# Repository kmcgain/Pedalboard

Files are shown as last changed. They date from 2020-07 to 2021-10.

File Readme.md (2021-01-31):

# Pedal Board
## Introduction

After seeing [this post](https://forum.fractalaudio.com/threads/diy-axe-fx-foot-controller-for-50-open-project.119882) I decided to put together my own pedal board for controlling my Axe Fx III. Rather than having a single screen however to display current preset information I wanted a screen per button to provide context sensitive information on each function.

The design includes:
* 3x5 momentary footswitch, lcd screen pairs. 
  * The LCD screen is a 1.8" 128x160px TFT SPI (ST7735 driver). 
* 7 pin MIDI in/out + phantom power on input
* 2 1/4" expression pedal inputs
* 9v adapter input

Layout 1
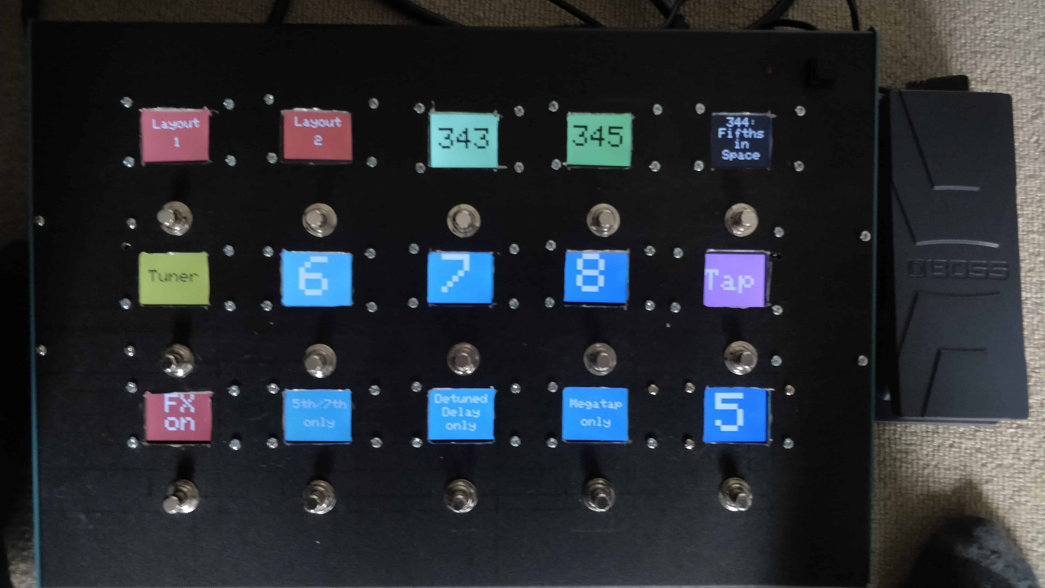
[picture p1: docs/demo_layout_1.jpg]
Layout 1


Layout 2
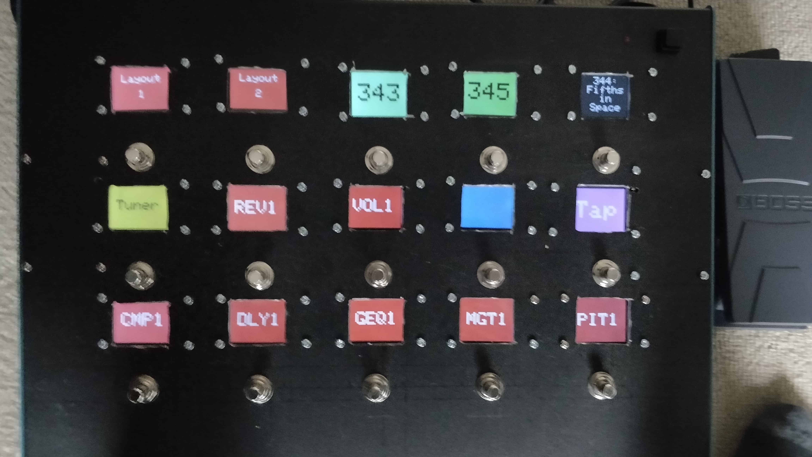
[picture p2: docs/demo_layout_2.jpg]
Layout 2


### Micro-controller
The Arduino Due was chosen due to the number of pins available, support for controlling many SPI devices concurrently, increased clock-speed over the Arduino Mega.

### Construction
A standard hammond enclosure was used, CAD designs were developed using FreeCad and available under [docs](docs). Note these designs were used to get a sense of proportions, layout. The designs aren't comprehensive and the final layout was not millimetre perfect.

[View the circuit diagram](docs/schematic.png)

## Software
The software was written from scratch with the exception of the great [Tysonit library](https://forum.fractalaudio.com/threads/arduino-axe-fx-control-library.147477/) and included Arduino libraries.

Current tweaks to out of the box software:
* Increased Arduino Due buffer size in {User folder}\AppData\Local\Arduino15\packages\arduino\hardware\sam\1.6.12\cores\arduino\RingBuffer.h to 512
* TFT Screen 
    - Need to modify User_Setup file for tft_eSpi lib. - {My Documents}\Arduino\libraries\TFT_eSPI\User_Setup.h
    - You can find my version of these settings at config/User_Setup.h

## Features
NOTE: Some of the below are still in development (marked in italics)
* Button short press, long press, hold
  * Hold allows for streaming multiple actions as opposed to long press which is an instantaneous single function - for example increase volume in increments while holding (I haven't yet assigned to any function..)
  * Functions can be assigned independently and screens will display these assignments independently
* Layouts
  * A layout is a set of functions assigned to buttons
  * A function can be assigned to switch layouts
* Functions
  * Preset/scene increment,decrement,select. Can increment/decrement by 1 or more. Select allows for an arbitrary preset/scene number to be selected eg. jump to preset 100
  * Expression pedal switch
    * *Although 2 expression pedals are supported, if you want to use 1 pedal but switch between controlling volume, wah, pitch or others a button press can do this - effectively changing expression pedal 1/2 to become 1-4.* (TODO)
  * Tap tempo - LED on front panel in sync
  * Tuner toggle + tuner display
  * Mute button
  * Stomp box - bypass drive, delay and other functions
    * Display colour per type, dimmed display when already bypassed  

### Design choices
Button presses signalled by interrupts - priority given to recording presses rather than screen updates / sending axe messages. 

A tape data structure is used for recording button events. This just creates a loop so if more button events occur in between processing cycles than we can fit in memory it will write over the earliest recorded events. This gives preference to processing the last action rather than dropping the latest actions if there is overflow as would be the case with a straight array implementation.

Core domain project is not coupled to Arduino or Tysonit. This allows for unit testing of the majority of the solution. The unit tests need to be extended further.

### Getting Started
After cloning the repository, use the following scripts to work with the program:
build.ps1 (does a single build of the code, no arduino needed)
upload.ps1 (this will build and upload to the arduino. It will ask you to select the com port used by arduino)
monitor.ps1 (you can run this independently of uploads to read the log output from the arduino)

Please visit the [Build Tutorial](docs/tutorial.md) for information on how to construct your own system
For details on how to work with the software visit [Software Tutorial](docs/tutorial-software.md)

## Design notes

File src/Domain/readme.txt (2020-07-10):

Shared Cross Platform C++ Project : For more information see http://www.visualmicro.com

Arduino shared projects allow code to be shared in multiple projects.

It is important to 'Add' a 'Reference' to 'Shared Projects' from the master Arduino project that uses the shared code.

It is also important to understand that, during compilation, shared project code is combined in a temporary folder along with the main project code. Arduino compile usually involves a temp folder therefore this way of working ensures that code could be manually combined and developed with a different IDE in the future.

Visual Studio will display intellisense based on the platform/board that has been specified for the currently active "Startup Project" of the current solution.

The Arduino IDE will also compile code that exists in an \src sub folder and it's children. Adhering to the same structure will also protect your code and allow compilation outside Visual Micro or a custom build tool. 

Suggestion: Because code is combined during compilation duplicate source code file names can be avoided with by structuring code as follows:-

SharedProject1
	src\SharedProject1\SharedProject1.cpp
	src\SharedProject1\SharedProject1.h
	
SharedProject2
	src\SharedProject2\SharedProject2.cpp
	src\SharedProject2\SharedProject2.h
	
When combined into the temp build folder during build of MainArduinoProject1, the structure will end like this:-

MainArduinoProject1
MainArduinoProject1.ino
	src\SharedProject1\SharedProject1.cpp
	src\SharedProject1\SharedProject1.h
	src\SharedProject2\SharedProject2.cpp
	src\SharedProject2\SharedProject2.h

blog: http://www.visualmicro.com/post/2016/05/27/Sharing-code-between-projects.aspx

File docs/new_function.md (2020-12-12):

# How to add a new function

The example I'll use here is adding a mute function. 

## Requirements
* This function should by default by unmuted
* The screen should display 'Mute' when unmuted
* The screen should display 'Unmute' when muted
* Pressing the footswitch should:
  * Change the state from muted to unmuted and vice-versa
  * Send a CC message to Axe FX for CC# 100 with a value of 127 when unmuting and a value of 0 when muting

## Steps
1. Define a new function type in Domain/function/function_type.h and assign the next enum number
   1. Eg. ftMute = 14
2. Define a FunctionState type to store our Muted/Unmuted state. This will be stored against the Control and can be accessed during button execution or screen updates
   1. Function states are designed to be reused across functions so keep them generic. In our case we don't have a boolean based state so we introduce a ToggleFunctionState in Domain/function/function_state.h
   2. The new class should inherit from public Function
   3. It should have a boolean field to represet our toggle position and appropriate functions to modify / return this state.
3. Define a new function class in Domain/function called mute.h
   1. All functions must implement the Name, Type public functions and execute, createState protected functions
      1. Name can be "Mute"
      2. Type should be the new enum value ftMute
      3. createState will return the new ToggleFunctionState
      4. execute should implement the action to run when the button is pressed. In our case we know we need to update our toggle state so the screen can be updated, but also we need to talk to our AxeFx so we'll delegate to the AxeController for this job
4. Add a 'mute' function to Domain/axe_controller.h that accepts a boolean indicating if we should send a mute or unmute
5. Add a 'mute' function to Pedalboard/Axe/axe_controller.cpp
   1. The mute function will call axe.sendControlChange with a CC number of 100 and cc value of 127 or 0 based on toggle flag
6. Modify Domain/function/function_factory.h to add a Mute() function
7. Modify Domain/function/function_factory.cpp to add a Mute() function
   1. This will return a new instance of the MuteFunction we previously defined
8. Modify Domain/layout_definition.h to add a new FunctionName enum member for mute
   1. This is different to the function type - for example with scene selection we have multiple scene selection functions all of the same function type
9.  Modify Domain/layout_manager.cpp setup_functions function to call the function factory and store the mute function instance in the functions array
   2. this->functions[FunctionName::mute] = functionFactory->Mute();
10. Modify Domain/layout_manager.h functions field to increase the array size
   3. eg. Function* functions[32]; => Function* functions[33];
11. Update the Display logic in Pedalboard/tft_screen.cpp
    1. The DisplayFunction has a switch statement, add a case for the new function type ftMute
    2. You can cast the provided functionState to your ToggleFunctionState because you know Mute functions are associated with this kind of State
    3. Use the toggle state to then draw text on the screen using appropriate background / foreground colour
    4. You can switch colours based on the state as well
12. Add the new function to a layout
    1.  Modify settings.json and include 'mute' where you like
13. Upload the new code by running upload.ps1

That's it! A new function is now available

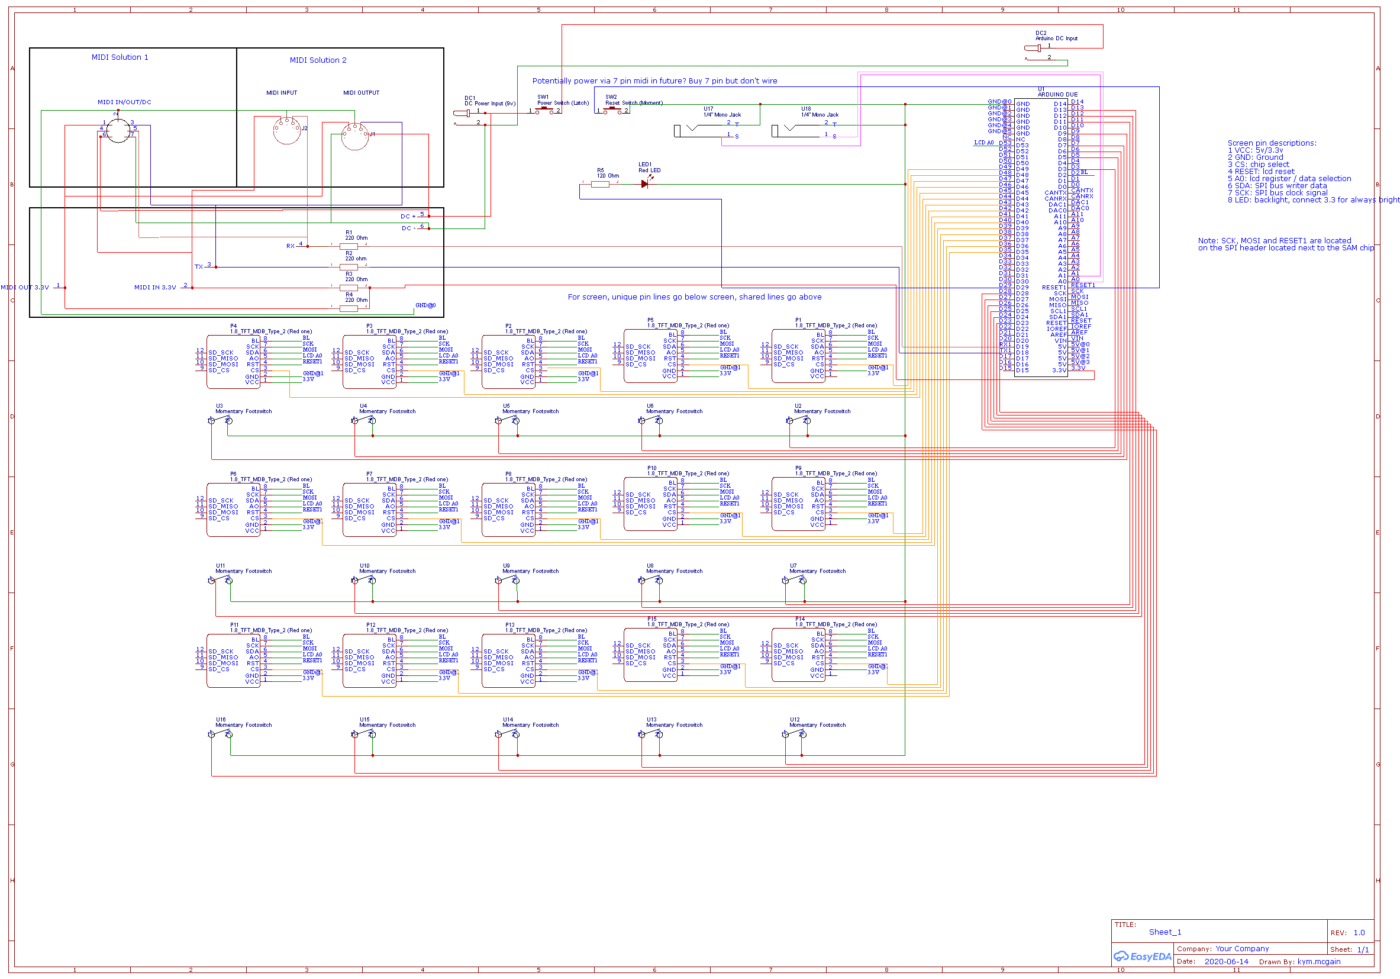
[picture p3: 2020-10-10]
docs/schematic_board.png

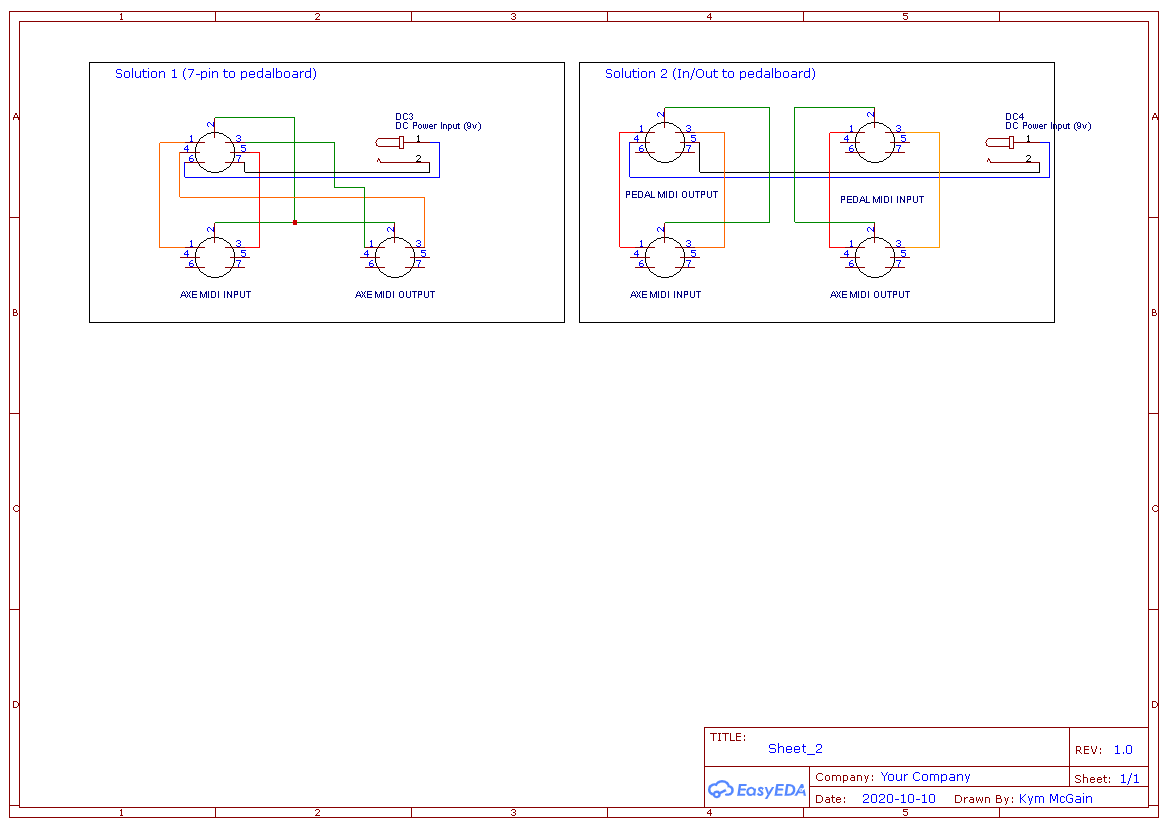
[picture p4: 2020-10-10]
docs/schematic_midibox.png

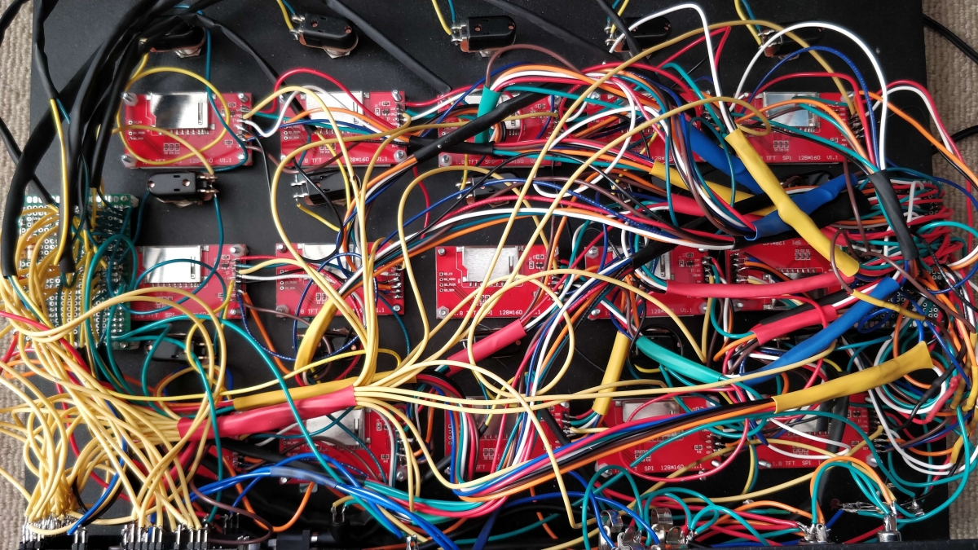
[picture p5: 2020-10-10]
docs/overview.jpg

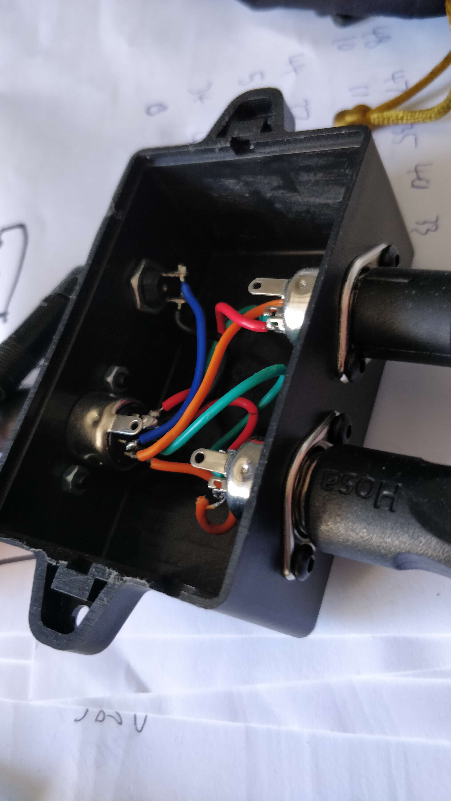
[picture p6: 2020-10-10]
docs/midi_anglee.jpg

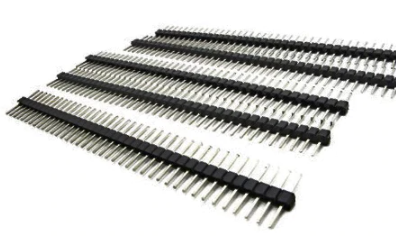
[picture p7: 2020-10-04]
docs/pin_headers.png

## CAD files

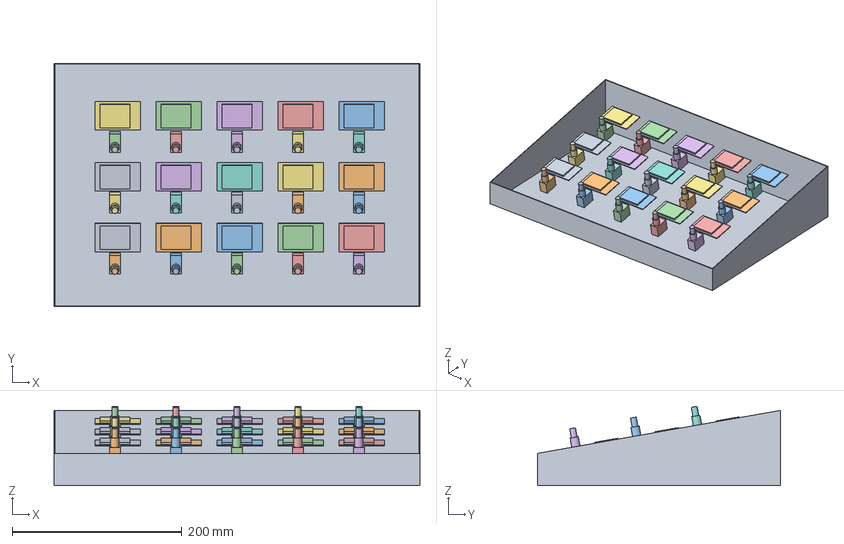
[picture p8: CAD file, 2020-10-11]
docs/PedalBoard.FCStd
431.8 x 287.0 x 93.7 mm
enclosure_001
Footswitch_001
Footswitch_002
Footswitch_003
Footswitch_004
Footswitch_005
Footswitch_006
Footswitch_007
Footswitch_008
Footswitch_009
Footswitch_010
Footswitch_011
Footswitch_012
Footswitch_013
Footswitch_014
Footswitch_015
screen_001
screen_002
screen_003
screen_004
screen_005
screen_007
screen_009
screen_010
screen_006
screen_008
screen_011
screen_012
screen_013
screen_014
screen_015

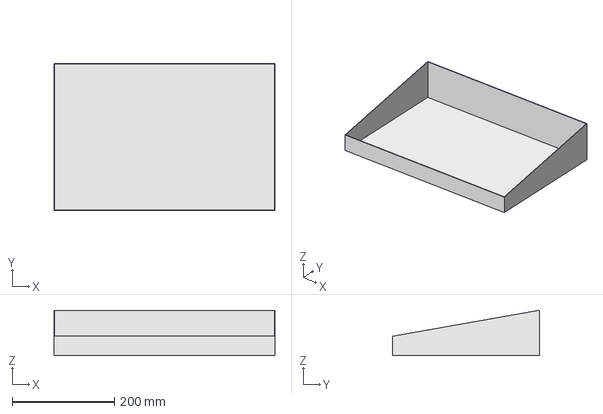
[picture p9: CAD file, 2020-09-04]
docs/enclosure.FCStd
431.8 x 287.0 x 88.9 mm

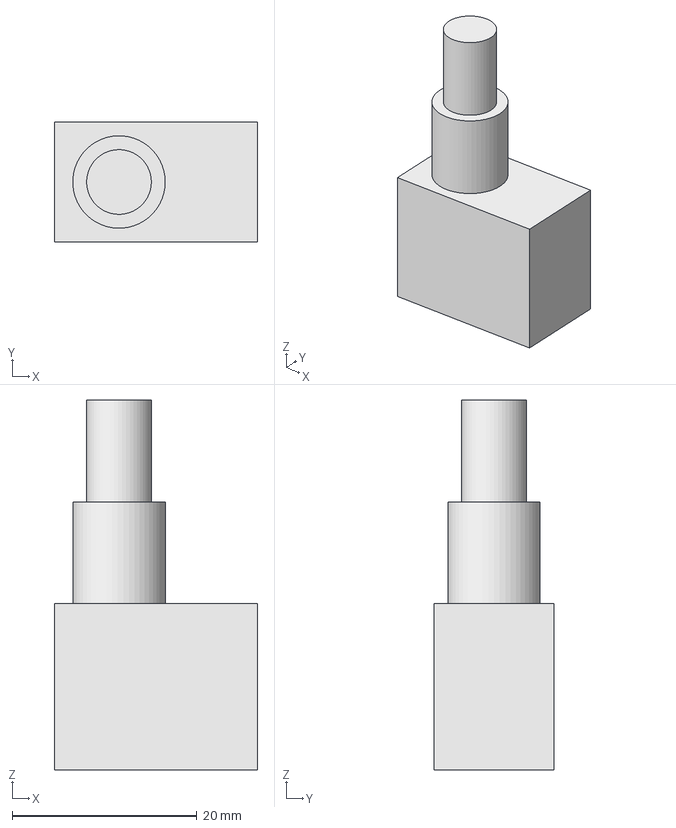
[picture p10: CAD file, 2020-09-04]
docs/Footswitch.FCStd
22.0 x 13.0 x 40.0 mm

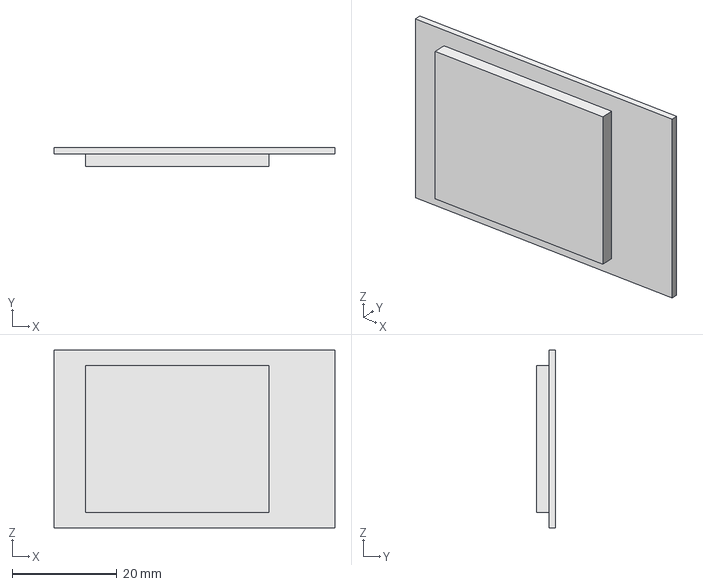
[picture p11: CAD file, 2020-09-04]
docs/screen.FCStd
53.7 x 3.55 x 34.0 mm

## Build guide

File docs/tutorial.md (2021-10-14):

# Parts required
## Pedalboard
I've included shipping costs as often this is a greater cost than the actual part ordered from AliExpress. You can load an image of the part from the link in description.

Prices will vary, only here as a guide on what to expect.

| Type | Count | Description | Price ($AUD) |
| --- | ---: | --- | ---: |
| Enclosure | 1 | [Hammond 1456RL1BKBU from mouser.com](hammond.png) | $71.70 |
| Arduino | 1 | [Work Good DUE R3 Board AT91SAM3X8E SAM3X8E 32-bit ARM Cortex-M3 Control Board Module For Arduino](arduino_due.png) | $19.49 |
| TFT Screen | 15 | [1.8 Inch TFT Color Screen LCD Display Module Drive ST7735](tft_screen.png) | $69.35 |
| Footswitch | 15 | [1pcs SPST Momentary Soft Touch Push Button Stomp Foot Pedal Switch Electric Guitar Switch OFF-Momentary ON](footswitch.png) | $40.42 |
| DC Socket | 1 | [3A 12v For DC Power Supply Jack Socket Female Panel Mount Connector 5.5mm 2.1mm Plug Adapter 2 Terminal Types 5.5*2.1](dc_socket.png) (1) | $1.37 |
| USB Socket | 1 | [Micro USB USB 2.0 Male Connector To Micro USB 2.0 Female Extension Cable 30cm 50cm With Screws Panel Mount Hole](usb_socket.png) | $4.36 |
| Pin headers | 2(10pc total) | [5pcs Pins Multipurpose: Male- 10pcs 40 Pin 1x40 Single Row Male Breakable Pin Header Connector Strip for Arduino](pin_headers.png) | $3.01 |
| PCB board | 2 | [5x7cm 5*7 Double Side Prototype PCB diy Universal Printed Circuit Board](pcb_board.png) (2 used) | $4.84 |
| Dupont cables | 2 | [120PCS 40PIN 20CM Dupont line male to male + female and female to female bridge Dupont Wire Cable for Arduino DIY KIT](dupont.png) (Get all variants) | $5.98 |
| DIN socket | 1 (1 needed) | [10PCS 3/4/5/6/7/8PIN Panel Mount Female Jack DIN Adapter MIDI Cable Connector](din_socket.png) (1 for pedalboard) | $6.16 |
| Heatshrink | 2 | [5 METER/LOT BLACK 1mm 1.5mm 2mm 2.5mm 3mm 3.5mm 4mm 5mm 6mm Heat Shrink Tubing Tube](heatshrink.png) (10m required) | $2.92 |
| Breadboard | 1 | [MB102 Breadboard Power Module+MB-102 830 Points Solderless Prototype Bread Board](breadboard.png) | $2.38 |
| Plastic Nuts | 2 (~160 needed) | [100pcs/lot M2 M2.5 M3 M4 M5 M6 M8 M10 Black or white Nylon Hex Nut Hexagon Plastic Nuts](plastic_nut.png) (M3) | $9.26 |
| M3 screws | 2 | [50PCS ISO7380 black button head screw M2 M2.5 M3 M4 M5 M6 M8 Hexagon Socket round head Screws Hex Socket Screw](screws.png) **(M3 20mm)** | $7.64 |
| M3 screws | 1 | [50PCS ISO7380 black button head screw M2 M2.5 M3 M4 M5 M6 M8 Hexagon Socket round head Screws Hex Socket Screw](screws.png) **(M3 50mm)** | $4 |
| Exp 1/4" TRS Socket | 2 | [6.5MM CHASSIS SOCKET STEREO/SWITCHED](trs_socket.png) | $4.02 |
| Wire |  | Get multi-color 22AWG ideally 8 different colours 25m each? |
| Latching switch (power button)  | 1 | [SPST Latching](switch_latching.png) | $3 |
| Momentary switch (reset switch) | 1 |[SPST Momentary](switch_momentary.png) | $3 |
| Resistor 220ohm |4 | Resistors for midi circuit 
| Resistor 120ohm |1| Resistor for tempo LED 
| 2mm Red LED |1| LED for tempo flash 

Notes:
* The dupont cables and breadboard are optional as they are used for testing.
* The TRS sockets must be switched - meaning when you plug the cable in it lifts 1 contact off another. This allows the analog inputs to be grounded when the cable is unplugged (more on this later in the tutorial)
* TRS sockets - you need as many as the number of expression pedals you want to run
* Plastic nuts - it's important not to use metal as they will be used in places that may short a circuit

## Midi power box
| Type | Count | Description | Price ($AUD) |
| --- | ---: | --- | ---: |
| Enclosure  | 1 | [22 Sizes Top Quality ABS Plastic Waterproof Cover Project Electronic Project Box Instrument Case Enclosure Boxes 8 Sizes](enclosure_midi.png) (black 82x52x35mm) | |
| DC Socket  | 1 | [3A 12v For DC Power Supply Jack Socket Female Panel Mount Connector 5.5mm 2.1mm Plug Adapter 2 Terminal Types 5.5*2.1](dc_socket.png) (1) | $0.00 |
| DIN socket | 1 (3 needed) | [10PCS 3/4/5/6/7/8PIN Panel Mount Female Jack DIN Adapter MIDI Cable Connector](din_socket.png) (7 pin) | $0.00 |

Sourced pretty much everything else off aliexpress, I'll provide descriptions so hopefully a search will find the right things (in case my links don't work).
Switches: 1pcs SPST Momentary Soft Touch Push Button Stomp Foot Pedal Switch Electric Guitar Switch OFF-Momentary ON
Screens: 1.8" TFT SPI ST7735

# Tools
I won't list prices / specifics here, just generally what you will need.

* Dremel/Rotary tool + 5-10 cut off wheels (anything appropriate for metal cutting - perhaps invest in durable cutters)
* N95 respirator (Essential when cutting aluminium with power tools) 
* Protective glasses
* Allen keys / Screw drivers for screws
* Wire strippers
* Soldering station
* A lot of solder (narrow)...
* Spanner
* Drill bit set
* Stepped drill bits or hole saws for cutting holes big enough for DIN sockets

# Software
Install FreeCad (I used version 0.18)

# Part 1 - Enclosure preparation
## Preparation
We will be using a rotary tool to cut out the square holes. To have a stronger solution we need to drill the corners of the squares first and then cut between them. So we want to start by marking out the corners of the screens on the face of the enclosure - use a center punch if you have 1 or mark with pencil / other marker.  

Open docs/PedalBoard.FCStd in FreeCad to get an overview of the board and where the footswitches / screens will be placed. 
Open screen.FCStf and then double-click screen/Body/Pad001/Sketch to see the detailed sketch. The inner block is the screen section that should be visible and will be the size of the hole we make in the enclosure.
The dimensions of the screen are 35.04mm x 28.03mm. It's also worth noting that the bottom left start of the screen is 6mm above and 2.985mm to the right of the bottom left of the screen board.
You can choose to divide up the space for your screens / switches yourself or you can use exact placement from the CAD design. To use exact placement:
* Select the top down view in FreeCard for the PedalBoard model
* Select the face of a screen and then view the 'Placement'. [Screenshot](screen_placement.png)
* You can now add these numbers together to get an X,Y position for the first screen:
  1. 54.44mm,67.725mm 
  2. 89.48mm,67.725mm
  3. 89.48mm,85.755mm
  4. 54.44mm,85.755mm
* You can repeate this process for every screen and record the co-ordinates in excel (use a basic function to calculate the wholes for each screen). Or you can find your own method :)
* For the footswitches we just need to find a center point to drill out
* Use the same method for the footswitches however this is much easier as you can just use an X co-ordinate of the screen X1 + (35.04 / 2). The Y co-ordinate can be Y1 - C where C is a constant value of 22.3mm
  
We now need to mark the positions for the arduino, PCB boards and other ports
* I mounted 2 PCB boards either side of the screens. See [photo](enclosure_inside_pcb.png)
* You can lay the PCB flat on the encsloure and center punch through the board holes
* This can be repeated for the arduino as well. The Arduino Due has 6 holes tht should be marked
* For other components I just placed these roughly - dc power, 1 DIN, 2 TRS sockets (for expression pedals), 1 reset switch. [Photo](back_components.png)

## Cutting, Drilling etc
Important: You should wear the N95 respirator + safety glasses as this stage - particularly when cutting aluminium as it creates a fine dust that will destroy your lungs.

* The screen corner holes can now be drilled with a small drill bit (2mm or less).
* Use the rotary tool with metal cutting disc attachment to cut between the drill holes
* Use a file, followed by sandpaper (anything around 100 grit will be fine) to clean up cuts and remove any sharp edges
* Use a drill to create a pilot hole for the footswitches and other components and then use the stepped drill bit to increase size until component fits - have a component handy to test as you cut
* Use a 1.5mm drill bit to create a hole for the led (that shows tempo time)
  * Use the led to test for appropriate size here. Use super glue to attach the led in place

## Extra support
I found that after removing the material for the screens the enclosure had become weaker so using footswitches would bow the top panel. I've addressed this to an acceptable level by adding some extra brackets to support the top panel. [Photo](bottom_panel.png)
I won't go into detail on this as you will need to place these according to your specific enclosure. The brackets can be found at any hardward store.

You should now have your enclosure prepared ready for assembly.

# Assembly
# PCB boards
Use long m3 screws through the enclosure into the PCB board. My boards had a tight thread so I did not need to use a nut on top to hold in place. However I did need a nut against the enclosure to keep the PCB in place. [photo](enclosure_inside_pcb.png)

These boards will actually be soldered on the back so these may remain loose / be removed throughout the project while adding other components.

## Screens
The first decision to make is whether you will be soldering against the pin headers of your screens or removing the pin headers (perhaps your screens don't have them pre-installed). Removing the pin headers will give you a more secure connection, however this is quite a painful task so I decided to leave them on and rely on the strength of the solder. If you want to remove them you should do so now. 

To install the screen we need to ensure we don't short the board against the aluminium enclosure, so we use plastic stand-off nuts. This means we have, bolt through the enclosure, onto a plastic stand-off, screen and then plastic standoff to secure the screen down. You repeat this for the 4 screen holes.

[Photo](screen_side.jpg)

If you need to install some upside down due to space / reverse them at a later stage while soldering this is actually ok. We can reverse them in the software.

## Switches
This is straight forward as the switches should have been threaded and come with their own washers/nuts. Use the second nut to set the height of the footswitch - make sure the switch circuit board does not sit directly against this nut. Get the nut fingertight on top of the enclosure and tighten with spanner (don't use too much force here).

## Arduino
The arduino will come with female pin headers for easy prototyping. For the most secure finish you should desolder these and solder wires straight onto the board. However I recommend doing this after the project is completely tested - we will use a more temporary solution through this tutorial allowing easy swappout of the arduino board if there are any issues / misconfiguration.

Like the screens you should use plastic stand-offs beneath the board and on top to secure it without shorting anything. I needed to use 2 between enclosure and board. You may find the gaps between pin headers are too small to rotate a nut, so use a screw-driver to tighten these. If any gaps are too small to even fit a nut, then see how secure the board is with the other holes locked down. You can always file down the plastic nuts to fit into the gaps as I did. [Photo](arduino_side.png)

## Other components
The other components will be similar to the footswitches - a simple matter of securing with provided nuts. The DIN sockets I used did require me to drill some holes and secure with screws. Just ensure you leave a bit of space between the components to make life easy when soldering these later.

# Electronics
[View the wiring](schematic_board.png)
The moral of this story is think hard about cable management and do a better job than me! I used shrink tube fairly extensively, I had planned on using brackets to run the wires in a neater way, but I didn't really leave enough wire length to make this work and didn't really want to redo the wiring.

You can import [schema](1-Schematic_PedalBoard.json) into EasyEda to modify as needed.

## Midi
Refer to [schematic](schematic_board.png) on how to wire this. 
* Solder wires onto the DIN socket according to schematic - the wires need to be long enough to reach the PCB, use all different colours and pass through shrink tube as a group to keep neat.
  * NOTE: We'll use 1 PCB for the midi connections and footswitches as there is plenty of space
* Use a multi-metre to test that none of the pins are connected to each other (have infinite resistance)
* Mount the resistors on the PCB board, the legs go through the holes and can be soldered in.
  * Leave a gap of 2 holes in between the resistors if mounting in a row
* Clip off the legs of the resistors so they don't short against anything
* Solder wires from DIN socket onto PCB
  * For the side that needs to connect to the Arduino I would recommend soldering in a pin header rather than a wire directly. This allows you to use dupont (female to female) to easily test
* On the back-side of the PCB solder in a [bridge](solder_bridge.png) between where you connected to wire, and the leg of resistor
* For the 3.3v midi lines you can bridge the 2 resistors (on the side connecting to arduino, not the side connecting to midi) and bridge this to a pin header to connect to arduino

[PCB frontside](midi_resistor.jpg)
[PCB backside](pcb_solder_bridge.jpg)
[Midi socket](midi_dc_in_2.jpg)

## Footswitch
Rather than connecting the footswitches directly to the arduino it is better to wire the footswitches to a PCB, this allows for using dupont cables for testing / changing pin numbers per switch easily
The ground will be bridged together so you have some options here. You can wire every footswitch to the PCB and then use a solder bridge across these and a pin header. The pin header can then be connected to the arduino easily. 
There will be many other components such as Midi, LED, screens that will all be bridged on ground as well so it's a good idea to have this happen on the PCB and then run 1 connection to the arduino.
If you want to save some wire you can daisy chain the switches together - for each row connect the grounds together in a line and then 1 wire per row onto the PCB to finally bridge and go to arduino.

The other terminal on the footswitch will correspond to a unique pin so can't be bridged. Solder in a pin header, wire each footswitch to the PCB hole next to each pin, then bridge from the back of the PCB - ensuring not to bridge any pins together.
You should use a multi-metre to test every pin forms a circuit when the switch is pressed. You should also check that none of the pin headers have continuity (infinite resistance).

### Connecting to arduino
There are a few pins that we can't use on the arduino as they interfere with SPI / have other purposes. D0/D1 are skipped purely because they can be used as additionaly Serial port. Pins 4, 8, 10, 14 should be left unconnected. So footswitch pins will be 3,5,6,7,8,11,12,13,22,23,24,25,26,27,28

Why?
- Pin 2 for PWM screen brightness
- Pin 4 Connected to MOSI SPI pin
- Pin 8 interferes with SPI reset
- Pin 9 controls led output
- Pin 10 is used for SPI slave mode

## Screens
The screens have 8 pins, of which only 1 is unique per screen (the CS pin). The rest will all be bridged together. In my design I wired every screen for 7 pins back to a PCB (separate PCB to the one used by footswitches + midi). This results in a grid of 15 (number of screens) x 7. The rows use a solder bridge and then a pin header at the end of the rows allowing a single connection per screen pin type back to the arduino. 

[PCB](screen_pcb.jpg)

However, I would recommend a different approach here. Daisy chain the screen rows together per pin type and then back to the PCB. This means you will only have 3 (number of rows) by 7 wires connecting to the PCB.

### Connecting to arduino
3 screen pins need to be connected to the SPI header on the board. See [location](spi_header.png):
Reset/RST => Reset
SCK => SCK
SDA => MOSI

The remaining screen pins:
BL => Digital Pin 2
AO => Digital Pin 53
CS => (digital pins 49-33 unique per screen, I left pins 50+ for other uses incuding the AO)
GND => Connect to any ground pin on arduino
VCC => Should connect to the 3.3v pin on arduino

NOTE: the screens can run on 5v as well, I believe this may increase brightness so am planning on experimenting with this.

## Expression
TODO

## LED
I have digital pin 29 assigned to a tempo LED.
* LEDs have polarity so you may need to reverse this circuit
* Twist and solder a 120 ohm resistor onto 1 leg of resistor and connect to pin 29, the other leg to connect to ground
  * Wire the ground to the footswitch PCB for easy central place for ground connections that are already bridged

Check the [schematic](schematic_board.png)
[Photo](led.jpg)

# Midi-Box
TODO: Details
[Schematic](schematic_midibox.png)
[Image](midi_box.jpg)

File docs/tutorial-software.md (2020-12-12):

# Setup
We need to install a few external libraries.

Adafruit GFX Library 1.10.1
AxeFxControl 1.1 
You can download this from [https://github.com/tysonlt/AxeFxControl/archive/v1.1.zip](AxeFxControl) and extract to C:\Program Files (x86)\Arduino\libraries\AxeFxControl (or appropriate location on mac/linux)
I have included a modified version of Adafruit_ST7735 library
* Their latest version does not work with my screens - corrupt display, haven't found the reason yet.
* Their library adds a lot of uncessery sleeping during initialisation and screen writing. It's essentially a naive implementation to try to be more reliable (less bad screen writes).
 * TODO: Try to get onto the latest version + contribute back the performance improvements

# Midi Settings 
The software uses midi channel 1 and makes a few other assumptions. Here are the recommended settings to change on the AxeFx->Setup->MIDI/Remote
* General / Midi Channel: 1
* General / Send Realtime Sysex: On
* General / Program Change: On
* General / Send Midi PC: CHAN 1
* General / Initial Value / External Control 1/2: 100% (This is optional but recommended so if you don't have an expression pedal plugged in your patches default to 100% volume etc)
* External / External Control # 1: CC #1
* External / External Control # 2: CC #2
* Other / Output 1 Volume: CC #2 (using external control 2 as the global volume)
  * This is convenient as you don't need to explicitly add a volume pedal into your chain, however this gives you a linear volume control that doesn't work too well - I've disabled this to use a logarithmic curve on the volume pedal
  * We could easily implement this in the pedal as well however on hold for now

# Layouts
If you want to setup your own layouts then just modify src/Domain/layout_definition.h 

# Adding new functions
[How to add a new function](new_function.md)

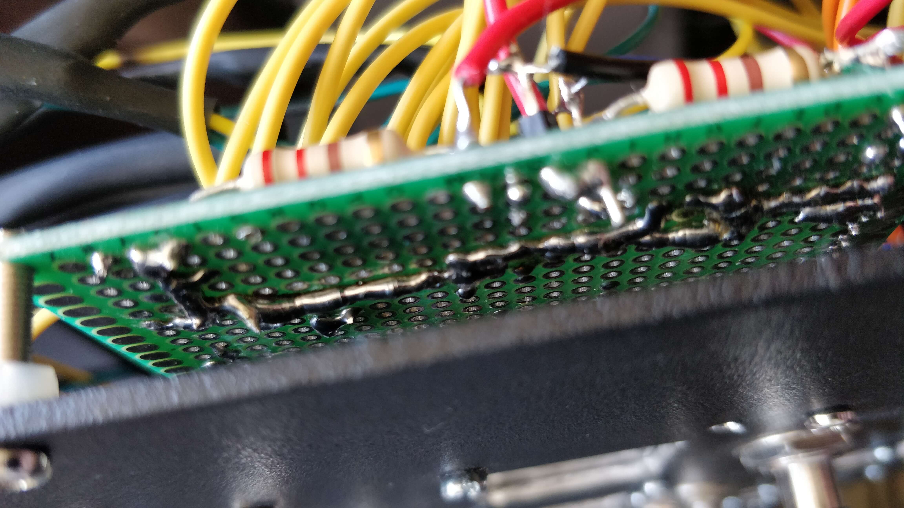
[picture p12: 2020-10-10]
docs/pcb_solder_bridge.jpg

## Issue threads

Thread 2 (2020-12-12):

Preset selector - breaks after switching layouts

kmcgain, 2020-12-12:
Steps to reproduce:
1. Press layout increment and wait to load
2. Press layout increment (to go back to first layout) and wait to load
3. Press scene select
4. Press back

Expected:
To show the standard layout

Actual:
Back button does nothing

Additionally, in this broken state you can continue to select presets and AxeFx will change, but after selection it just goes back to the first preset select page.

kmcgain, 2021-02-14:
Rewrote preset select function so the above is no longer relevant.

Closed 2021-02-14.

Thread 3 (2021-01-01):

Midi not working with the latest Build  [downloaded on 2-1-2021 | 00:05 CET Europe time)

Axelman8, 2021-01-01:
After testing with the piing flash V7,  i got the midi working.  Patch and scene change working.  Tuner and Tap tempo working. Front panel AxeFx changes are working with the midi connection.

Downloaded and Flashed a brand new version of your latest build but the midi is not responding to button presses.

Axelman

Axelman8, 2021-02-13:
Hey there,
Got Midi working.  In my pinset-up  i have got serial (tx-rx) instead of serial1 (tx1-rx1).
Changed your build code to serial and it is working flawlessly.  (axe_controller.cpp line 83

Axelman8

Closed 2021-02-13.

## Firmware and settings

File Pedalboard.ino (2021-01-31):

#define DEBUG
#define DEBUG_LOG

typedef unsigned char byte;

#include "src/Domain/layout_manager.h"
#include "src/Domain/interrupt_manager.h"
#include "src/Domain/interrupt_registrar.h"
#include "src/Domain/layout_setup.h"
#include "src/Domain/worker_process.h"
#include "src/Domain/axe_controller.h"
#include "src/Domain/screen_factory.h"
#include "src/Domain/preset.h"
#include "src/Domain/tuner.h"

#include "generated/settings.h"
#include "src/Domain/pedal_settings.h"

#include <ArduinoJson.h>

#include <malloc.h>
#include <stdlib.h>
#include <stdio.h>


#include <TFT_eSPI.h>
#include <SPI.h>

extern char _end;
extern "C" char *sbrk(int i);
char *ramstart=(char *)0x20070000;
char *ramend=(char *)0x20088000;

#define TAP_TEMPO_LED_PIN 29

uint32_t lastTime, startTime;
WorkerProcess* workerProcess;  
volatile unsigned long tapTempoPulseTime = -1;
bool tempoLedOn = false;
Preset* currentPreset = nullptr;
TunerData tuner;
  
void onTapTempo() {
  tapTempoPulseTime = millis();
}

void onPresetChange(Preset* axePreset) {
  currentPreset = axePreset;
}

void onTunerData(const char* note, const short string, const short fineTune) {
  strcpy(tuner.Note, note);
  tuner.FineTune = fineTune;
  tuner.String = string;
}


#ifdef __arm__
// should use uinstd.h to define sbrk but Due causes a conflict
extern "C" char* sbrk(int incr);
#else  // __ARM__
extern char *__brkval;
#endif  // __arm__
 
int freeMemory() {
  char top;
#ifdef __arm__
  return &top - reinterpret_cast<char*>(sbrk(0));
#elif defined(CORE_TEENSY) || (ARDUINO > 103 && ARDUINO != 151)
  return &top - __brkval;
#else  // __arm__
  return __brkval ? &top - __brkval : &top - __malloc_heap_start;
#endif  // __arm__
}

void printf(const char* fmt, va_list args) {
  char buf[15];
  sprintf(buf, fmt, args);
  Serial.print(buf);
}

void ShowMemory(void)
{
  
  struct mallinfo mi=mallinfo();

  char *heapend=sbrk(0);
  register char * stack_ptr asm("sp");

  printf("Estimated Free RAM: %d\n\n",stack_ptr - heapend + mi.fordblks);
}


void setup() {    
  Serial.begin(9600); 
  while (!Serial);

  Serial.print(F("Setting up\n"));

  analogReadResolution(12);
  pinMode (A0, INPUT);
  pinMode (A1, INPUT);
  
  // Light up the screens
  pinMode(2, OUTPUT);
  digitalWrite(2, HIGH);

  // Setup tempo led
  pinMode(TAP_TEMPO_LED_PIN, OUTPUT);  

  // Load settings
  auto error = deserializeJson(PedalSettings, jsonSettings);
  if (error) {
    Logger::log("Failed to setup due to bad settings");
    return;
  }
  
  //buffer = new ScreenBuffer();

  auto layoutChanger = new LayoutChanger();
  auto axeController = new AxeController();
  axeController->Init(onTapTempo, onPresetChange, onTunerData);
  auto exp1 = new Expression(1, axeController);
  auto exp2 = new Expression(2, axeController);
  registerLayoutManager(new LayoutManager(new FunctionFactory(layoutChanger, axeController), layoutChanger, new ScreenFactory(), exp1, exp2));
    
  InterruptRegistrar* interruptRegistrar = new InterruptRegistrar();
  BoardConstants boardConstants = BoardConstants();
  boardConstants.Rising = RISING;
  boardConstants.Falling = FALLING;
  boardConstants.Change = CHANGE;
  
  GetLayoutManager()->init();
  setup_interrupts(interruptRegistrar, boardConstants);  

  workerProcess = new WorkerProcess(axeController, exp1, exp2);

  start_recording();

  Serial.print(F("Setup complete\n"));
  startTime = millis();
  lastTime = millis();

  #ifdef DEBUG
    ShowMemory();
  #endif
}

void loop() { 
#ifdef DEBUG
  if (millis() - lastTime > 3000) {
    lastTime = millis();
    Logger::log("Alive\n");    
    ShowMemory();
  }
#endif

  // More time for setup to run??
  //if (millis() - 3100 > startTime) {
    if (!tempoLedOn && tapTempoPulseTime != -1) {
      digitalWrite(TAP_TEMPO_LED_PIN, HIGH);
      tempoLedOn = true;
    }

    if (tempoLedOn && tapTempoPulseTime < millis()-50) {
      tapTempoPulseTime = -1;
      digitalWrite(TAP_TEMPO_LED_PIN, LOW);
      tempoLedOn = false;
    }

    workerProcess->OneStep(currentPreset, tuner);

  Logger::flush();
}

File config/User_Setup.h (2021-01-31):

// See SetupX_Template.h for all options available



#define ST7735_DRIVER


#define TFT_WIDTH  128
#define TFT_HEIGHT 160


#define ST7735_BLACKTAB

// For ST7735, ST7789 and ILI9341 ONLY, define the colour order IF the blue and red are swapped on your display
// Try ONE option at a time to find the correct colour order for your display

//  #define TFT_RGB_ORDER TFT_RGB  // Colour order Red-Green-Blue
//  #define TFT_RGB_ORDER TFT_BGR  // Colour order Blue-Green-Red

// For NodeMCU - use pin numbers in the form PIN_Dx where Dx is the NodeMCU pin designation
#define TFT_DC  53  // Data Command control pin
#define TFT_RST  8    // Set TFT_RST to -1 if the display RESET is connected to NodeMCU RST or 3.3V

#define LOAD_GLCD   // Font 1. Original Adafruit 8 pixel font needs ~1820 bytes in FLASH
#define LOAD_FONT2  // Font 2. Small 16 pixel high font, needs ~3534 bytes in FLASH, 96 characters
#define LOAD_FONT4  // Font 4. Medium 26 pixel high font, needs ~5848 bytes in FLASH, 96 characters
#define LOAD_FONT6  // Font 6. Large 48 pixel font, needs ~2666 bytes in FLASH, only characters 1234567890:-.apm
#define LOAD_FONT7  // Font 7. 7 segment 48 pixel font, needs ~2438 bytes in FLASH, only characters 1234567890:.
#define LOAD_FONT8  // Font 8. Large 75 pixel font needs ~3256 bytes in FLASH, only characters 1234567890:-.
#define LOAD_FONT8N // Font 8. Alternative to Font 8 above, slightly narrower, so 3 digits fit a 160 pixel TFT
#define LOAD_GFXFF  // FreeFonts. Include access to the 48 Adafruit_GFX free fonts FF1 to FF48 and custom fonts
#define LOAD_Custom //custom 

#define SMOOTH_FONT


// #define SPI_FREQUENCY  20000000
//#define SPI_FREQUENCY   27000000
//#define SPI_FREQUENCY     40000000
#define SPI_FREQUENCY   24000000

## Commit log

2020-06-27 Initial modelling of layouts / pin setups
2020-06-28 Add Button with debounce, push, long push, hold
2020-07-26 End to end test working for pressing button and having it delegated to axe fx function
2020-08-14 Fix bugs with interrupts. Starting refactor to make volatile Tape
    [Pedalboard.ino]
2020-08-15 Tweaked button press algorithm, now working with real buttons
2020-08-15 All pins now working for buttons
2020-08-16 Completed algorithm for buttons - now reliable
2020-09-04 Implement tft screen Add docs + cad + circuit diagram
    [Footswitch.FCStd, PedalBoard.FCStd, enclosure.FCStd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]
2020-09-07 Locked in button and screen pin numbers, working prototype
2020-09-10 Stop writing low to pin 13 to switch led - currently used for button
2020-09-27 Fix button handling by suppressing extra pushes after releases
2020-09-28 Add current preset name display
2020-09-28 Fix bug with first press on switch
2020-09-30 Implemented workaround for stall in scene name loading
    [Pedalboard.ino]
2020-09-30 Fix directory structure
    [Footswitch.FCStd, PedalBoard.FCStd, enclosure.FCStd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]
2020-10-10 Fix arduino docs
2020-10-11 Fixed some issues with loading of scene / preset data
    [PedalBoard.FCStd]
2020-11-01 Fix display issue of expressions switch.
    [Pedalboard.ino]
2020-11-10 Wrote new screen driver - works better for fast full screen updates, however not good for fast partial screen updates like tuner. Will use new driver as base and add better support for tuner.
2020-11-15 Update display driver so it has 2 modes - full screen batch and fine grained update. Batch mode is best to quickly update a full screen, but fine grained is needed for tuner where we only need to ren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
2020-11-22 Fix up the unit tests
    [Pedalboard.ino]
2020-11-24 Fix settings file generation - remove bom
2020-12-12 Refactored char to use byte (unsigned char). Moved button pin numbers into settings file
2020-12-12 Moved screen pin numbers to settings file
2021-01-31 Switched to new tft lib. Still working on preset display and tuner
2021-01-31 Fixed tuner for new display
    [Pedalboard.ino, User_Setup.h]
2021-03-21 Move position of preset select paging buttons to the bottom right for easier use
